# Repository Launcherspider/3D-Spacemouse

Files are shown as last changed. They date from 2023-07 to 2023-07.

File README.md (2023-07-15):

# **DIY 3D Space Mouse** <sub>*for OnShape, Fusion 360 and more*</sub>
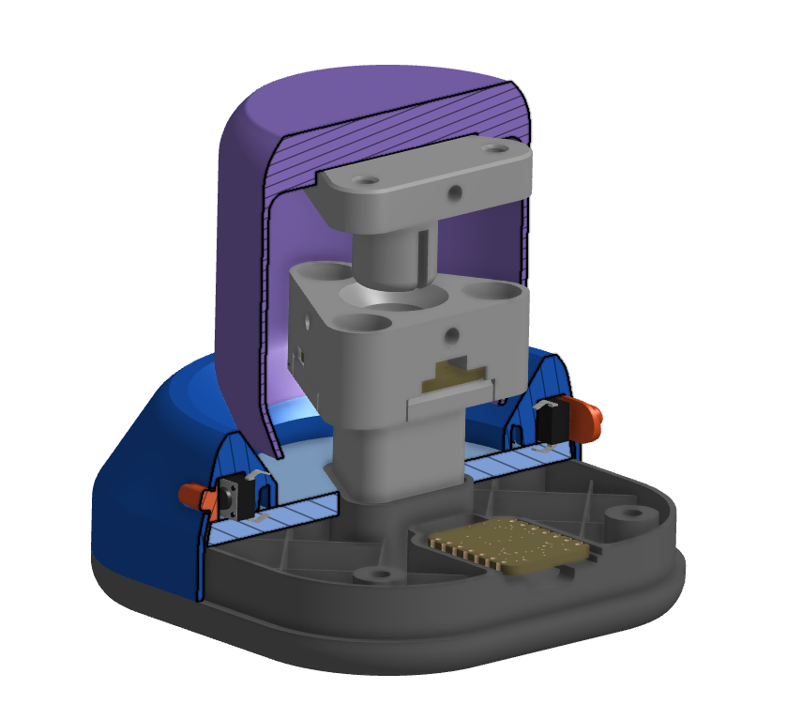
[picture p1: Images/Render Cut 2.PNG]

This Input device is made for OneSape.com and Fusion360 but can be adapted to other CAD applications. Current features: Orbit, Pan, Home view and normal/fit view.

[](https://youtu.be/iHBgNGnTiK4)
⇦Build video from sb-ocr

[]([https://youtu.be/iHBgNGnTiK4](https://www.instructables.com/DIY-Space-Mouse-for-Fusion-360-Using-Magnets))
⇦Build instructions

## **Fork update:**

I changed the code, so it works in OnShape and similar CAD applications. I used AI to help me, since I do not code usually.

All the Stl and Step files are replaced. I optimized it for 3D printing. 
The mouse can be assembled directly after printing, no support material needed. See Print_All.stl for optimal orientation.
The Base_bottom can be filled after printing no pausing needed. I used plaster to weighten the Base. Steel would be better, lead would be best.



## How to use
Ones connected the knob can be used to pan (aka moveing the object/camera in all directions on the view plane) by tilting the it in the appropriate direction.
By punshing the knob down (lightly), the orbiting mode gets activated (aka rotating the object/camera around the central point).
The buttons are corrently just set to tip a "**n**" or "**f**", but can be changed to every chaine of keyboard or mouse input. [Reference](https://www.arduino.cc/reference/en/language/functions/usb/keyboard/keyboardmodifiers/)

## Libraries needed:
```
TinyUSB_Mouse_and_Keyboard.h
BLE52 Mouse and Keyboard.h
OneButton.h
Tlv493d.h
SimpleKalmanFilter.h
```

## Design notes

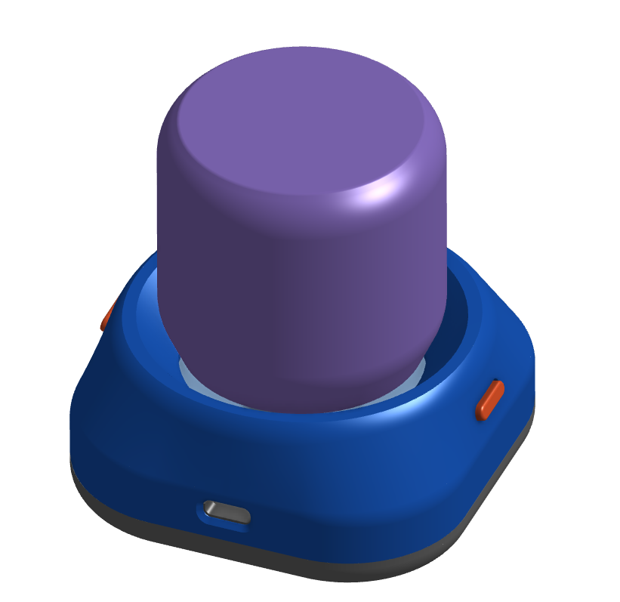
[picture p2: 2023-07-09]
Images/Render.PNG

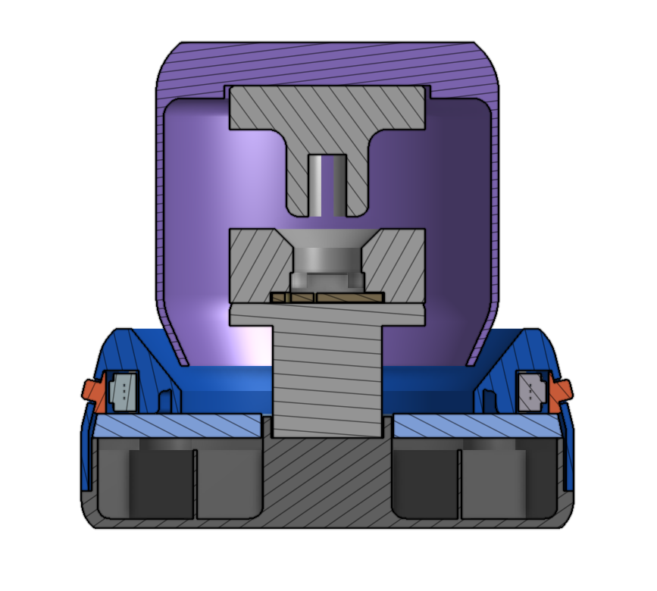
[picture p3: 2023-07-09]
Images/Render Cut.PNG

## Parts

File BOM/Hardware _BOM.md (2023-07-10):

Qty|             Item.            |    Notes.    | Place
5  |Round Magnets (6 × 2mm)       |     ---      |
3  |Compression Spring 9 × 35mm   | 0.7mm thick  |
3  |Extension Spring 5 x 20mm     |0.5mm tick,relaxed 8mm|
4  |M2 × 3.5 mm Heat-Set Inserts  |     ---     |
14 |M3 × 4-5mm Socket Head Screws |     ---     |
4  |M2 × 10mm Socket Head Screws  |     ---     |Stem_Middle
3  |M3 × 6mm Socket Head Screws   |     ---     |Knob+Base_Middle
3  |M3 × 8mm Socket Head Screws   |     ---     |Stem
4  |M3 × 12mm Socket Head Screws  |     ---     |Base_Top

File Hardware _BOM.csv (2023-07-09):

Qty | Item | Link
6 | Round Magnets (6 × 2mm) | https://geni.us/0oCmMH
3 | Compression Spring 23/64" × 1-3/8" | https://geni.us/mm5tB
3 | Extension Spring 13/64" × 13/16" | https://geni.us/mm5tB
24 | M2.5 × 3.4 mm Heat-Set Inserts | https://geni.us/BMZYH
10 | M2.5 × 3mm Socket Head Screws | https://geni.us/S0KvnqZ
3 | M2.5 × 5mm Socket Head Screws | https://geni.us/S0KvnqZ
7 | M2.5 × 8mm Socket Head Screws | https://geni.us/S0KvnqZ
4 | M2.5 × 12mm Socket Head Screws | https://geni.us/S0KvnqZ

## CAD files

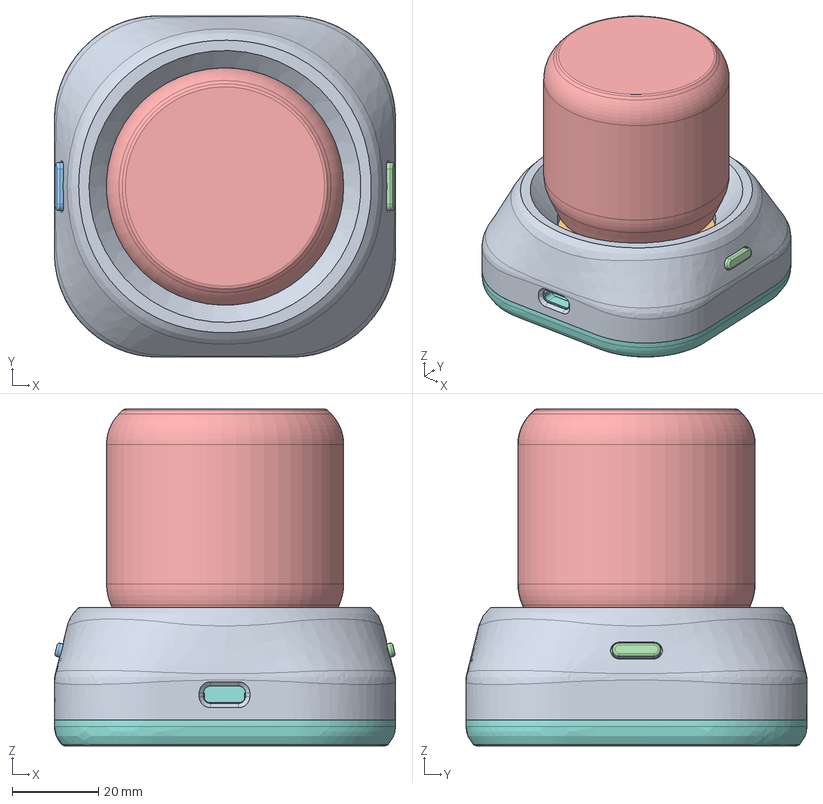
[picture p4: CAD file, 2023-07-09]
CAD/STEP/3D Mouse.step
79.0 x 79.0 x 78.0 mm

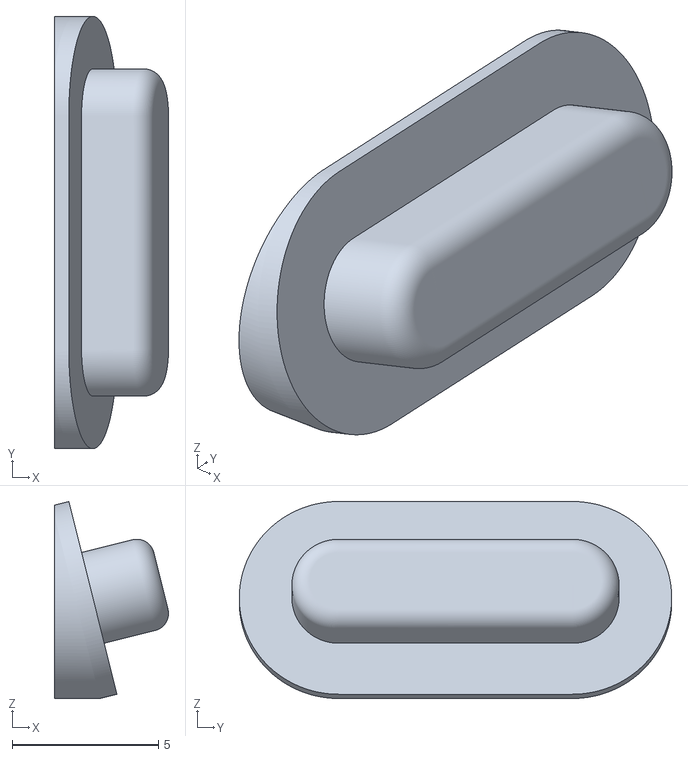
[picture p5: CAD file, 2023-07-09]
CAD/STLs/Buttons.stl
3.90 x 14.8 x 6.74

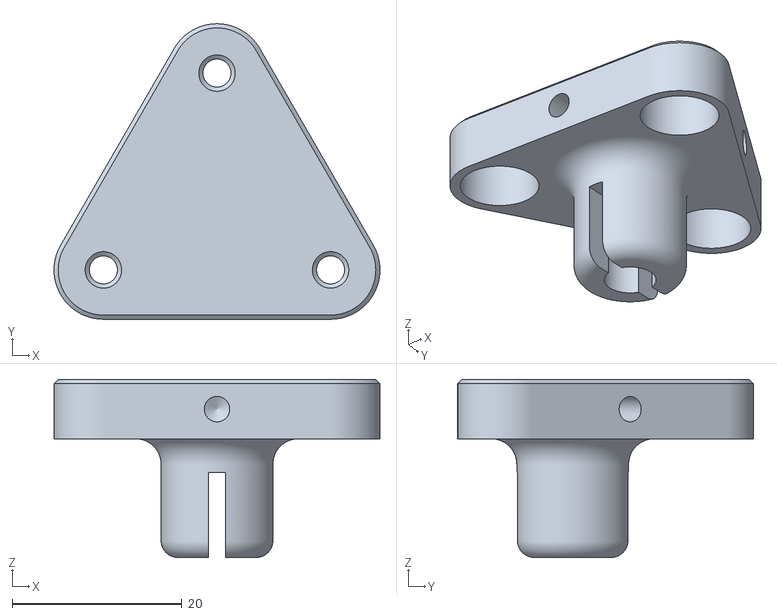
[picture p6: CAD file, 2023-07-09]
CAD/STLs/Stem_top.stl
38.5 x 34.9 x 21.0

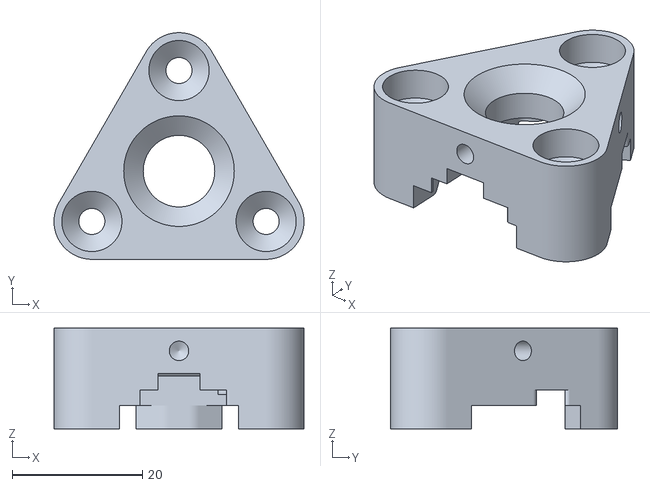
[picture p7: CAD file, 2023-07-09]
CAD/STLs/Stem_middle.stl
38.5 x 34.9 x 15.5

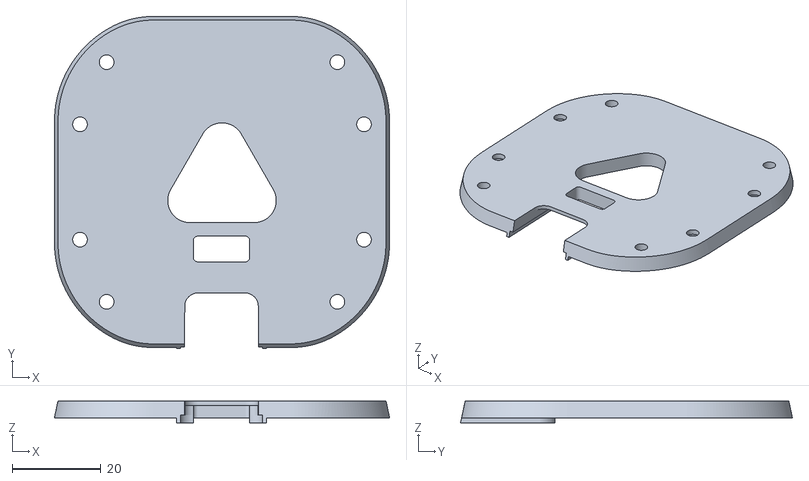
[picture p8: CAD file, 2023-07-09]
CAD/STLs/Base_middle_plate.stl
75.6 x 74.8 x 4.88

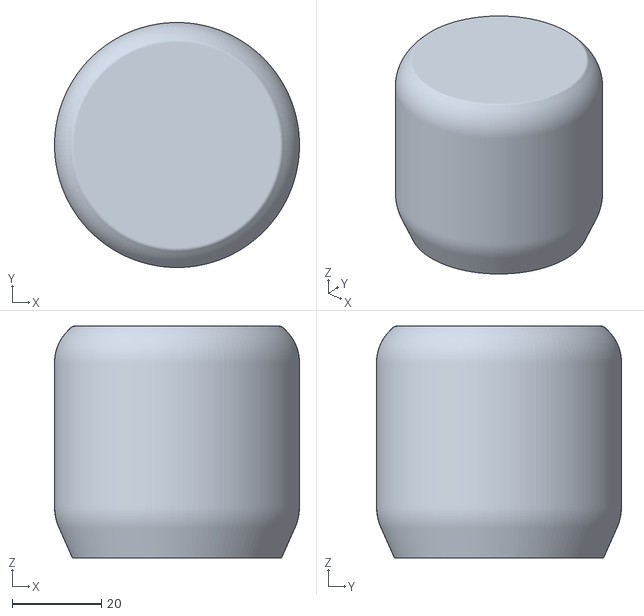
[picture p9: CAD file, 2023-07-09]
CAD/STLs/Knob.stl
55.0 x 55.0 x 52.0

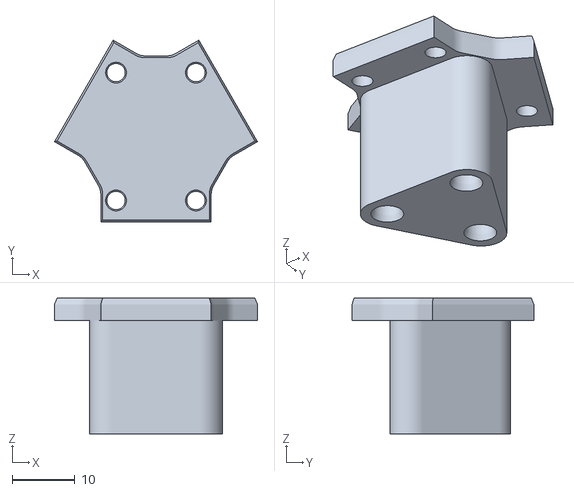
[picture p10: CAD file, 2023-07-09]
CAD/STLs/Stem_bottom.stl
32.3 x 28.9 x 21.6

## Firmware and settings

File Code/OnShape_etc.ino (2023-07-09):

#include <TinyUSB_Mouse_and_Keyboard.h>
#include <OneButton.h>
#include <Tlv493d.h>
#include <SimpleKalmanFilter.h>

Tlv493d mag = Tlv493d();
SimpleKalmanFilter xFilter(1, 1, 0.2), yFilter(1, 1, 0.2), zFilter(1, 1, 0.2);

// Setup buttons
OneButton button1(27, true);
OneButton button2(24, true);

float xOffset = 0, yOffset = 0, zOffset = 0;
float xCurrent = 0, yCurrent = 0, zCurrent = 0;

int calSamples = 300;
int sensitivity = 8; // Just initiative - adjust sensitivity later in code for orbit/pan
int magRange = 3;
int outRange = 127;      // Max allowed in HID report
float xyThreshold = 0.5; // Center threshold 0.4

int inRange = magRange * sensitivity;
float zThreshold = xyThreshold * 1.5;

bool isOrbit = false;

void setup()
{
  button1.attachClick(goHome);
  button1.attachLongPressStop(goHome);

  button2.attachClick(fitToScreen);
  button2.attachLongPressStop(fitToScreen);

  // mouse and keyboard init
  Mouse.begin();
  Keyboard.begin();

  Serial.begin(9600);
  Wire1.begin();

  // mag sensor init
  mag.begin(Wire1);
  mag.setAccessMode(mag.MASTERCONTROLLEDMODE);
  mag.disableTemp();

  // crude offset calibration on first boot
  for (int i = 1; i <= calSamples; i++)
  {
    delay(mag.getMeasurementDelay());
    mag.updateData();

    xOffset += mag.getX();
    yOffset += mag.getY();
    zOffset += mag.getZ();

    Serial.print(".");
  }

  xOffset = xOffset / calSamples;
  yOffset = yOffset / calSamples;
  zOffset = zOffset / calSamples;

  Serial.println();
  Serial.println(xOffset);
  Serial.println(yOffset);
  Serial.println(zOffset);
}

void loop()
{
  // keep watching the push buttons
  button1.tick();
  button2.tick();

  // get the mag data
  delay(mag.getMeasurementDelay());
  mag.updateData();

  // update the filters
  xCurrent = xFilter.updateEstimate(mag.getX() - xOffset);
  yCurrent = yFilter.updateEstimate(mag.getY() - yOffset);
  zCurrent = zFilter.updateEstimate(mag.getZ() - zOffset);

  // check the center threshold
  if (abs(xCurrent) > xyThreshold || abs(yCurrent) > xyThreshold)
  {
    int xMove = 0;
    int yMove = 0;

    // map the magnetometer xy to the allowed 127 range in HID reports
    xMove = map(xCurrent, -inRange, inRange, -outRange, outRange);
    yMove = map(yCurrent, -inRange, inRange, -outRange, outRange);

    // switching between orbiting and panning in OnShape and similar by observing zThreshold(zAxis)
    if (abs(zCurrent) < zThreshold && !isOrbit) // Joystick pressed down
    {
      Mouse.press(MOUSE_MIDDLE);  // Simulate middle mouse button press for panning
    }
    else if (abs(zCurrent) >= zThreshold && !isOrbit) // Joystick released
    {
      delay(20); // prevent random right clicks and crash
      Mouse.press(MOUSE_RIGHT);  // Simulate right mouse button press for orbiting
      sensitivity = 16; // higher=less_travel Adjust the sensitivity value as desired
      inRange = magRange * sensitivity;
      isOrbit = true;
    }

    // pan or orbit by moving proportionally to the xy axis
    Mouse.move(xMove, -yMove, 0);
  }
  else
  {
    // release the mouse and keyboard if within the center threshold
    Mouse.release(MOUSE_RIGHT);  // Release right mouse button
    Mouse.release(MOUSE_MIDDLE);  // Release middle mouse button
    Keyboard.releaseAll();
    sensitivity = 8; // reset the sensitivity value for panning
    inRange = magRange * sensitivity;
    isOrbit = false;
  }

  Serial.print(xCurrent);
  Serial.print(",");
  Serial.print(yCurrent);
  Serial.print(",");
  Serial.print(zCurrent);
  Serial.println();
}

// Set view to normal of sketch in OnShape (pressing "n")
void goHome()
{
  Keyboard.write('n');

  delay(10);
  Keyboard.releaseAll();
  Serial.println("normal view");
}

// fit to view by pressing the middle mouse button twice
void fitToScreen()
{
  // for OnShape press "f"
  Keyboard.write('f');

  delay(10);
  Keyboard.releaseAll();

  // for other CAD-softwar double "middle mouse click"
  // Mouse.press(MOUSE_MIDDLE);
  // Mouse.release(MOUSE_MIDDLE);
  // Mouse.press(MOUSE_MIDDLE);
  // Mouse.release(MOUSE_MIDDLE);

  Serial.println("fit view");
}

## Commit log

2023-07-09 Update and rename Hardware _BOM.csv to BOM/Hardware _BOM2.csv
    [Hardware _BOM2.csv]
2023-07-09 Update Hardware _BOM2.csv
    new Hardware BOM
    [Hardware _BOM2.csv]
2023-07-09 Delete Hardware _BOM.csv
    replaced
    [Hardware _BOM.csv]
2023-07-09 Update and rename Hardware _BOM2.csv to Hardware _BOM.csv
    [Hardware _BOM.csv]
2023-07-09 Update Hardware _BOM.csv
    [Hardware _BOM.csv]
2023-07-10 Update Hardware _BOM.csv
    Make it look nice
    [Hardware _BOM.csv]
2023-07-10 Create Hardware BOM
2023-07-10 Update Hardware BOM
2023-07-19 Update Hardware BOM
    Oopsy Heat-Set Inserts not screws
